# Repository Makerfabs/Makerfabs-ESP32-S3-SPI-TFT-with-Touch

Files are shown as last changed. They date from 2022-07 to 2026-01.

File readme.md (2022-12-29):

# Makerfabs ESP32-S3 SPI TFT with Touch

```c++
/*
Version:		V1.4
Author:			Vincent
Create Date:	2022/7/13
Note:
			2022/12/29	V1.4: Change wiki link
			2022/10/10	V1.3: Add Touch Keyboard demo and Back Light demo.
			2022/8/19	V1.2: Add hardware file.
			2022/8/18	V1.1: Add two demo.
			
*/
```
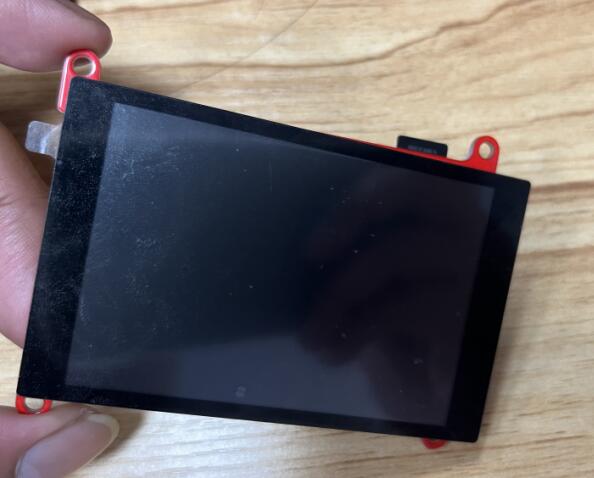
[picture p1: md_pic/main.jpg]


[toc]

# Makerfabs

[Makerfabs home page](https://www.makerfabs.com/)

[Makerfabs Wiki](https://wiki.makerfabs.com/)

# Makerfabs ESP32-S3 SPI TFT with Touch
## Intruduce

Product Link ：[ESP32-S3 SPI TFT with Touch 3.5'' ILI9488](https://www.makerfabs.com/esp32-s3-spi-tft-with-touch-ili9488.html)

Wiki Link : [ESP32-S3 SPI 3.5" TFT with Touch](https://wiki.makerfabs.com/ESP32_S3_SPI_3.5_TFT_with_Touch.html)

The 3.5" 320x480 TFT LCD driver is ILI9488, it uses SPI line for communication with ESP32-S3. You can freely use some of GPIO, to connect the ESP32-S3 display with sensors/ actuators, suitable for IoT applications.

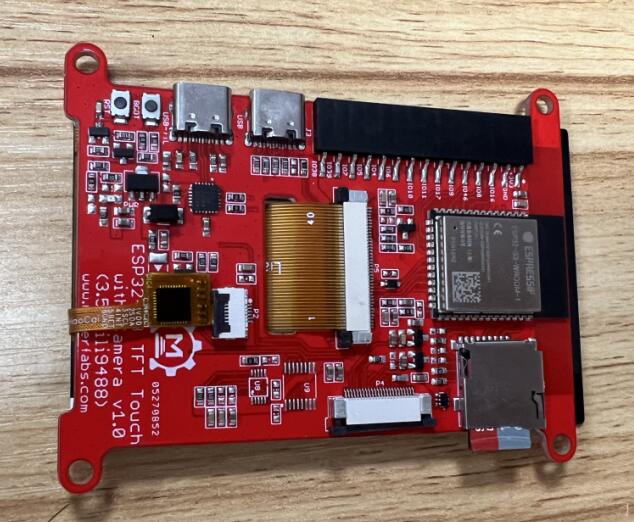
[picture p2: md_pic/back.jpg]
back


## Feature

- Wi-Fi (2.4 GHz band)
- Bluetooth Low Energy
- Dual high performance Xtensa® 32-bit LX7 CPU cores
- Ultra Low Power co-processor running either RISC-V or FSM core
- Multiple peripherals
- Built-in security hardware
- USB OTG interface
- USB Serial/JTAG Controller
- Arduino Compatible: You can play it with Arduino IDE
- LCD 3.5 inch Amorphous-TFT-LCD (Thin Film Transistor Liquid Crystal Display) for mobile-phone or handy electrical equipment
- LCD Driver: ILI9488(SPI)
- LCD Resolution: 320*480
- FT6236 Series ICs are single-chip capacitive touch panel controller IC with a built-in 16 bit enhanced Micro-controller unit (MCU)
- Power supply: 5V, Type-C USB
- Micro SD card slot on the board
- Dual USB Type-C: one for native USB and one for USB-to-UART
- Board size: 66mm * 85mm

# Code Explain

## Complier Option

- Install board : ESP32 .
- Install library : LovyanGFX library. 
- Use type-c use cable connect USB-TTL to PC.
- Upload codes, select "ESP32-S3 DEV Module" and "UART0"

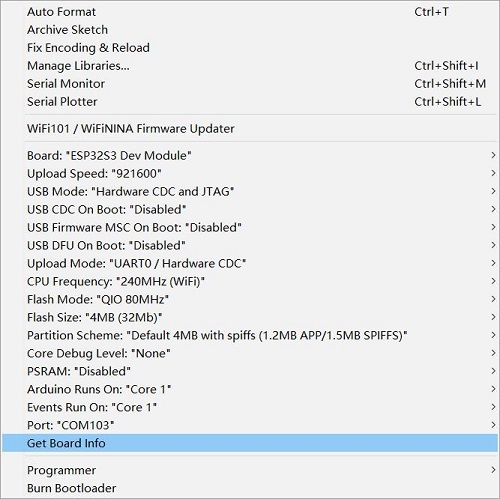
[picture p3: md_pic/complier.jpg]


## Firmware

### S3_9488

A simple test procedure. Touch the black area in the middle of the screen, and the screen starts showing solid colors in turn. Finally, an SD card image is displayed.

## Example

### image_display.ino

The BMP image of the SD card is displayed.

### indoor

[ESP32 Touch_Indoor Environment Expansion](https://www.makerfabs.com/esp32-touch-indoor-environment-expansion.html)

Test air temperature, humidity, and TVOC values with extension plate.

### Touch Keyboard

Added an inherited three custom keyboard keyboard Demo, including text input + key combination, numeric keypad, arrow keys + space.

### Back Light

Periodically adjust the brightness of the backlight

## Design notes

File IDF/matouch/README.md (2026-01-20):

# Example Description
This project includes example code for some MaTouch products.
- [**MaTouch 1.28" ToolSet_Controller**](https://www.makerfabs.com/matouch-1-28-toolset-controller.html)
- [**MaTouch_ESP32-S3 Parallel TFT with Touch 4.3"**](https://www.makerfabs.com/esp32-s3-parallel-tft-with-touch-4-3-inch.html)
- [**Makerfabs-ESP32-S3-SPI-TFT-with-Touch**](#makerfabs-esp32-s3-spi-tft-with-touch)
- [**Makerfabs-ESP32-S3-Parallel-TFT-with-Touch**](#makerfabs-esp32-s3-parallel-tft-with-touch)

This repository is suitable for the [**Makerfabs-ESP32-S3-Parallel-TFT-with-Touch**](#makerfabs-esp32-s3-parallel-tft-with-touch).

## How to use example
#### MaTouch 1.28" ToolSet_Controller
Select the development board as **1-28-gc9a01-cst816s** .

This example includes four routines：
> `main/firmware/1-28-gc9a01-cst816s/release.c`


- xuanniu_test：Example of a rotary encoder.
aadb7e029fc8b3403fd312ede316a084-ezgif.com-optimize
- template_image_switch_lvgl: Use LVGL's built-in libturbo-jpeg decoder to load JPG images from the SD card.
image_switch
- template_lvgl_demos_test: Examples included with LVGL.  
qq_pic_merged_1766452938301
- template_pcf8563_test: A simple PCF8563 RTC example.

#### MaTouch_ESP32-S3 Parallel TFT with Touch 4.3"
Select the development board as **4-3-unkonwn-gt911** .
clipboard_2025-12-22_23-23
This example includes two routines：

> `main/firmware/4-3-unkonwn-gt911/release.c`

clipboard_2025-12-22_23-2
- template_image_switch_lvgl: Use LVGL's built-in libturbo-jpeg decoder to load JPG images from the SD card.
ezgif.com-optimize
- template_lvgl_demos_test: Examples included with LVGL.
qq_pic_merged_1766453592919

#### Makerfabs-ESP32-S3-SPI-TFT-with-Touch

Select the development board as **3-5-ili9488-ft6236** .



This example includes two routines：

> `main/firmware/3-5-ili9488-ft6236/release.c`

```c
static void release_task(void *arg)
{
    template_image_switch_lvgl("/sdcard/images");
    // template_lvgl_demos_test();
    vTaskDelete(NULL);
}
```

- template_image_switch_lvgl: Use LVGL's built-in libturbo-jpeg decoder to load JPG images from the SD card.

  VID20251231133347-ezgif.com-optimize

- template_lvgl_demos_test: Examples included with LVGL.

  ezgif.com-optimize

#### Makerfabs-ESP32-S3-Parallel-TFT-with-Touch

Select the development board as **3-5-ili9488-ft6236** .



This example includes two routines：

> `main/firmware/3-5-ili9488-ft6236/release.c`

```c
static void release_task(void *arg)
{
    template_image_switch_lvgl("/sdcard/images");
    // template_lvgl_demos_test();
    vTaskDelete(NULL);
}
```

- template_image_switch_lvgl: Use LVGL's built-in libturbo-jpeg decoder to load JPG images from the SD card.

  VID20251231133347-ezgif.com-optimize

- template_lvgl_demos_test: Examples included with LVGL.

  ezgif.com-optimize

## Example Note

If using `template_image_switch_lvgl` example, the following options must be enabled in menuconfig.

> Modify line 64 of `managed_components/lvgl__lvgl/env_support/cmake/esp.cmake`:
>
> ```cmake
> REQUIRES esp_timer espressif__libjpeg-turbo)
> ```




If using the `template_lvgl_demos_test` example, enable different LVGL demos in menuconfig.


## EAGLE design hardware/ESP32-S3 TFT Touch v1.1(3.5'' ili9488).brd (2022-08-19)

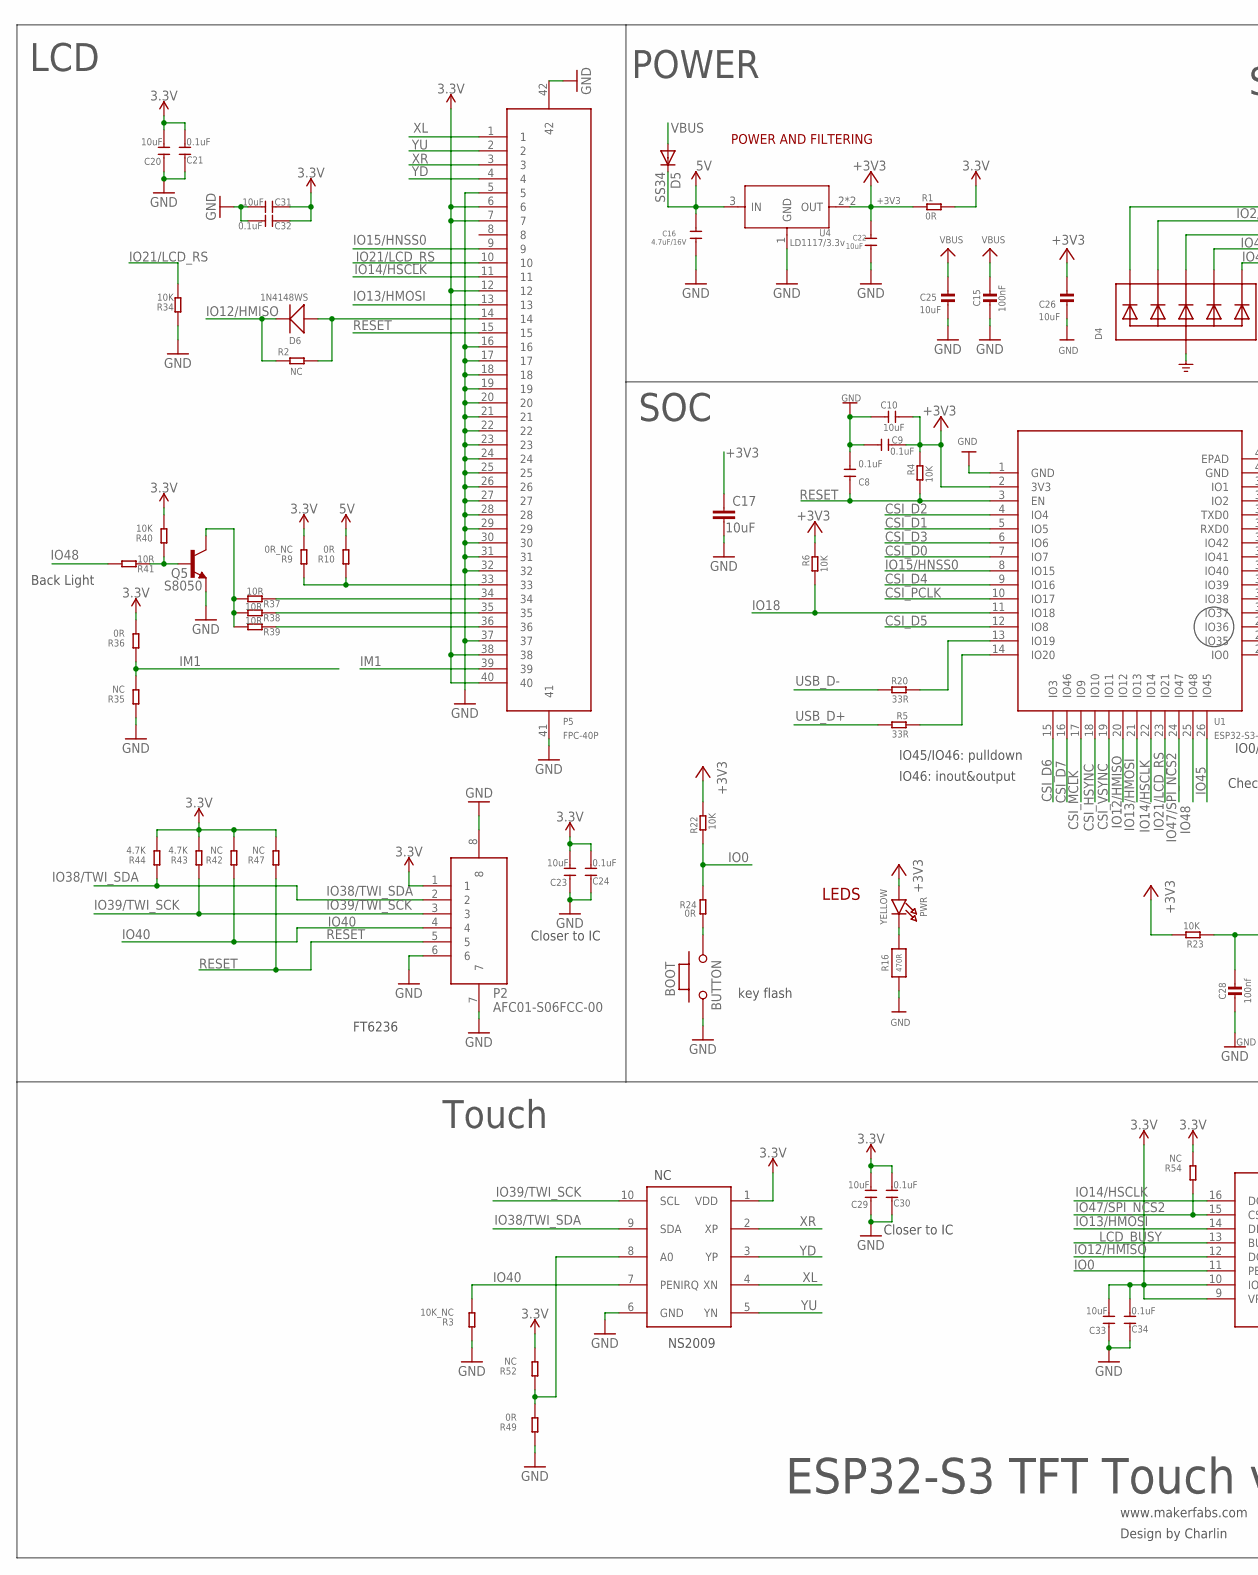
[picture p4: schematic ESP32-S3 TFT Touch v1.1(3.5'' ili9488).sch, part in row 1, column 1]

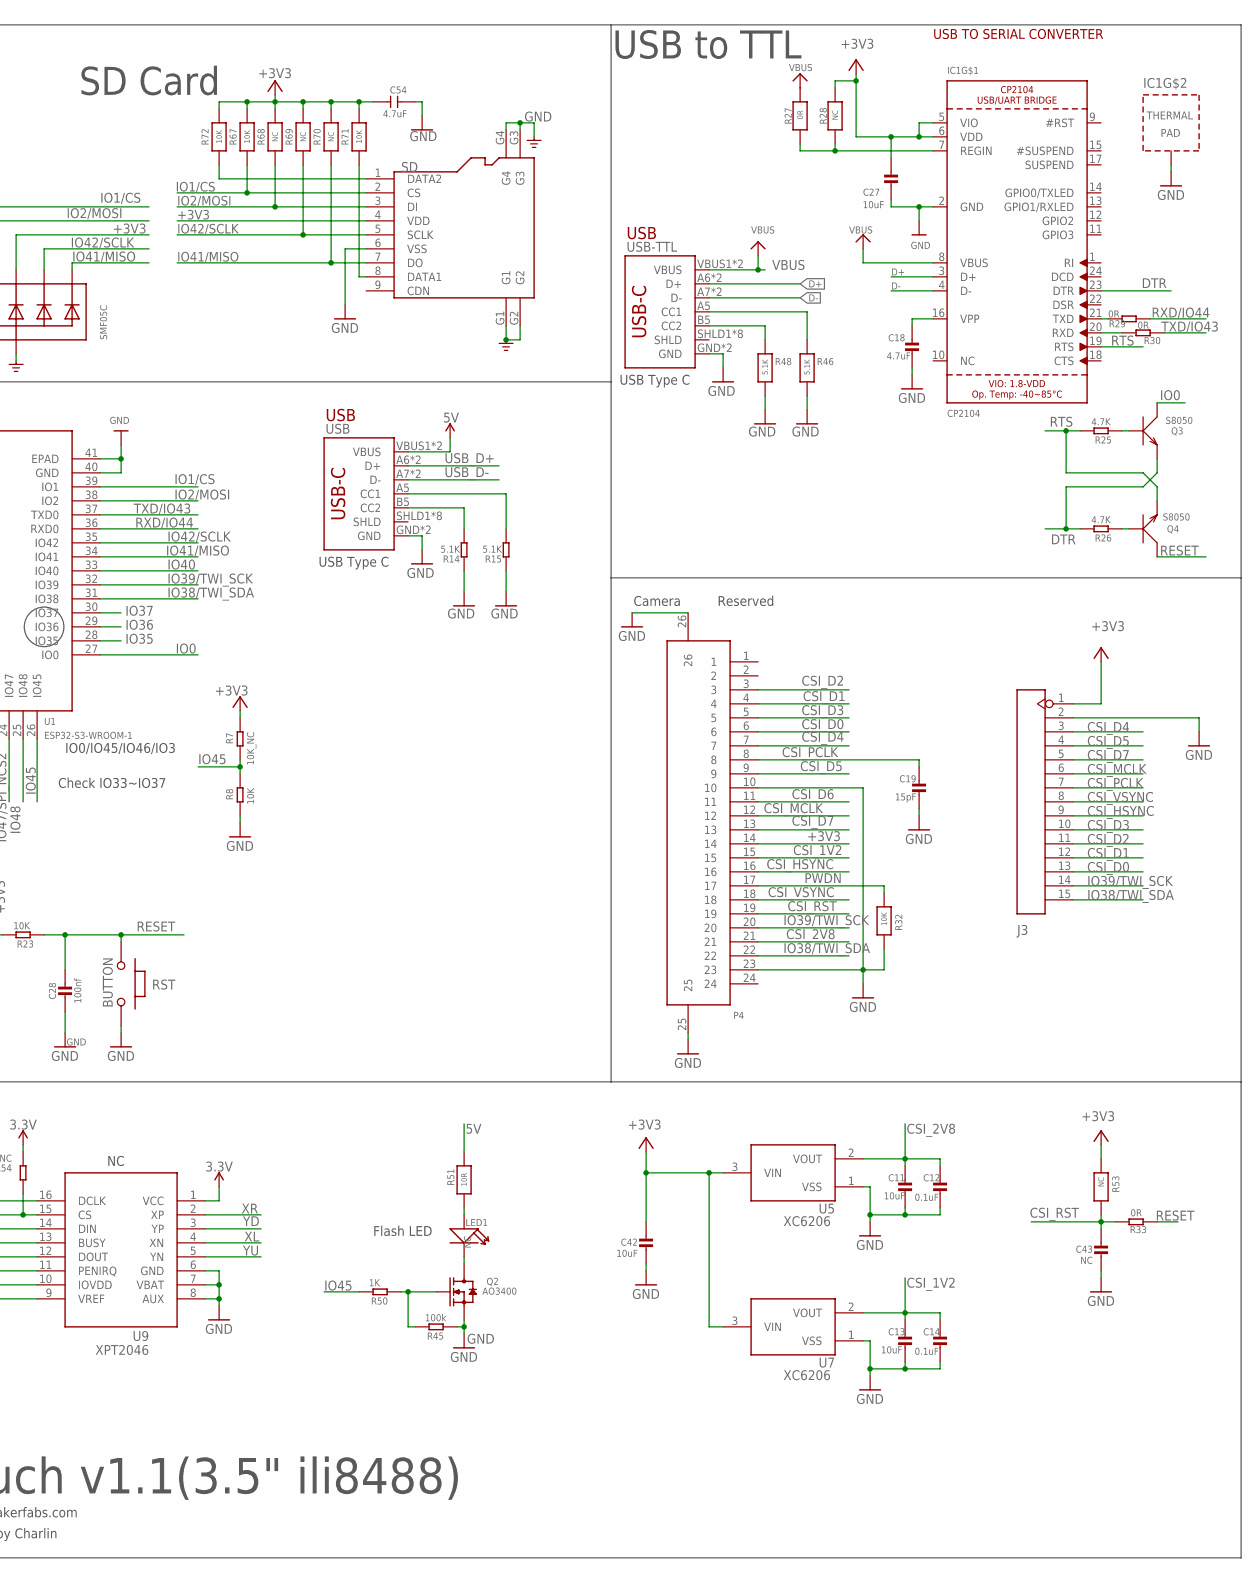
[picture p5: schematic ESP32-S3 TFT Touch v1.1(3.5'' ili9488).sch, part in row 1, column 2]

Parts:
BOOT: BUTTON; 157SW
C8, C9, C21, C24, C30, C32, C34: 0.1uF; DISCRETE_C0603
C10, C20, C23, C29, C31, C33: 10uF; DISCRETE_C0603
C11, C13, C25, C26, C27, C42: 10uF; 0603-NO
C12, C14: 0.1uF; 0603-NO
C15: 100nF; 0603-NO
C16: 4.7uF/16V; 0603
C17: 10uF; C0603
C18: 4.7uF; 0603-NO
C19: 15pF; 0603-NO
C22: 10uF; 0603
C28: 100nf; 0603-NO
C43: NC; 0603-NO
C54: 4.7uF; DISCRETE_C0603
D4: SMF05C; SOT363
D5: SS34; DO-214AC
D6: 1N4148WS; SOD323
IC1: CP2104; QFN24_4MM_SMSC
J3: HEADER-1X15P; SMD15-2.54P8.5H
LED1: NC; DISCRETE_LED-3528
P2: AFC01-S06FCC-00; SMD8-50P-740L535W
P4: FPC-24P; SMD26-50P-1760L450W
P5: FPC-40P; SMD42-50P-2560L490W
PWR: YELLOW; CHIPLED_0805_NOOUTLINE
Q2: AO3400; SOT23@1
Q3, Q4: S8050; SOT23
Q5: S8050; SPARKFUN_SOT23
R1, R24, R29, R30, R33: 0R; R0603
R2: NC; R0603
R3: 10K_NC; DISCRETE_R0603
R4, R6, R8, R22, R23: 10K; R0603
R5, R20: 33R; R0603
R7: 10K_NC; R0603
R9: 0R_NC; DISCRETE_R0603
R10, R36, R49: 0R; DISCRETE_R0603
R14, R15: 5.1K; DISCRETE_R0603
R16: 470R; 0603-NO
R25, R26: 4.7K; R0603
R27: 0R; 0603-NO
R28, R53, R68, R69, R70: NC; 0603-NO
R32, R67, R71, R72: 10K; 0603-NO
R34, R40: 10K; DISCRETE_R0603
R35, R42, R47, R52, R54: NC; DISCRETE_R0603
R37, R38, R39, R41: 10R; DISCRETE_R0603
R43, R44: 4.7K; DISCRETE_R0603
R45: 100k; R0603
R46, R48: 5.1K; 0603-NO
R50: 1K; R0603
R51: 10R; 0603-NO
RST: BUTTON; 157SW
SD: HOLDER-MICROSD-9P; 9P-SMD-W/-RING
U1: ESP32-S3-WROOM-1
U4: LD1117/3.3v; SOT89
U5, U7: XC6206; SOT-23
U8: NS2009; MSOP10
U9: XPT2046; TSSOP16-65P-560L910W
USB: USB_C5; USB-C-16P-5
USB-TTL: USB_C5; USB-C-16P-5

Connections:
3.3V: C20.2, C21.2, C23.2, C24.2, C29.2, C30.2, C31.1, C32.1, C33.2, C34.2, P2.1, P5.6, P5.7, P5.12, P5.38, P5.40, R1.2, R9.2, R36.2, R40.2, R42.2, R43.2, R44.2, R47.2, R52.2, R54.2, U8.1 (VDD), U9.1 (VCC), U9.9 (VREF), U9.10 (IOVDD)
5V: C16.1, D5.C, R10.2, R51.1, U4.3 (IN), USB.VBUS1 (VBUS), USB.VBUS2 (VBUS)
+3V3: C9.1, C10.1, C17.1, C22.1, C26.1, C27.1, C42.1, C54.2, D4.4 (C3), IC1.5 (VIO), IC1.6 (VDD), J3.1, P4.14, PWR.A, R1.1, R4.2, R6.2, R7.2, R22.2, R23.2, R28.1, R53.1, R67.2, R68.2, R69.2, R70.2, R71.2, R72.2, SD.4 (VDD), U1.2 (3V3), U4.2 (OUT), U4.4 (OUT), U5.3 (VIN), U7.3 (VIN)
CSI_1V2: C13.1, C14.1, P4.15, U7.2 (VOUT)
CSI_2V8: C11.1, C12.1, P4.21, U5.2 (VOUT)
CSI_D0: J3.13, P4.6, U1.7 (IO7)
CSI_D1: J3.12, P4.4, U1.5 (IO5)
CSI_D2: J3.11, P4.3, U1.4 (IO4)
CSI_D3: J3.10, P4.5, U1.6 (IO6)
CSI_D4: J3.3, P4.7, U1.9 (IO16)
CSI_D5: J3.4, P4.9, U1.12 (IO8)
CSI_D6: P4.11, U1.15 (IO3)
CSI_D7: J3.5, P4.13, U1.16 (IO46)
CSI_HSYNC: J3.9, P4.16, U1.18 (IO10)
CSI_MCLK: J3.6, P4.12, U1.17 (IO9)
CSI_PCLK: C19.1, J3.7, P4.8, U1.10 (IO17)
CSI_RST: C43.1, P4.19, R33.2, R53.2
CSI_VSYNC: J3.8, P4.18, U1.19 (IO11)
D+: IC1.3 (D+), USB-TTL.A6 (D+), USB-TTL.B6 (D+)
D-: IC1.4 (D-), USB-TTL.A7 (D-), USB-TTL.B7 (D-)
DTR: IC1.23 (DTR), Q3.2 (E), R26.2
GND: BOOT.1, C8.2, C9.2, C10.2, C11.2, C12.2, C13.2, C14.2, C15.2, C16.2, C17.2, C18.2, C19.2, C20.1, C21.1, C22.2, C23.1, C24.1, C25.2, C26.2, C27.2, C28.2, C29.1, C30.1, C31.2, C32.2, C33.1, C34.1, C42.2, C43.2, C54.1, D4.2 (A), IC1.2 (GND), IC1.THERM (TP), J3.2, P2.6, P2.7, P2.8, P4.10, P4.23, P4.25, P4.26, P5.5, P5.16, P5.17, P5.18, P5.19, P5.20, P5.21, P5.22, P5.23, P5.24, P5.25, P5.26, P5.27, P5.28, P5.29, P5.30, P5.31, P5.32, P5.37, P5.41, P5.42, Q2.2 (S), Q5.2 (E), R3.1, R8.1, R14.1, R15.1, R16.1, R32.2, R34.1, R35.1, R45.1, R46.2, R48.2, R49.1, RST.1, SD.6 (VSS), SD.G1, SD.G2, SD.G3, SD.G4, U1.1 (GND), U1.40 (GND), U1.41 (EPAD), U4.1 (GND), U5.1 (VSS), U7.1 (VSS), U8.6 (GND), U9.6 (GND), U9.7 (VBAT), U9.8 (AUX), USB.GND, USB.GND2 (GND), USB-TTL.GND, USB-TTL.GND2 (GND)
IM1: P5.39, R35.2, R36.1
IO0: Q3.3 (C), R22.1, R24.2, U1.27 (IO0), U9.11 (PENIRQ)
IO1/CS: D4.1 (C1), R67.1, SD.2 (CS), U1.39 (IO1)
IO2/MOSI: D4.3 (C2), R68.1, SD.3 (DI), U1.38 (IO2)
IO12/HMISO: D6.-, R2.1, U1.20 (IO12), U9.12 (DOUT)
IO13/HMOSI: P5.13, U1.21 (IO13), U9.14 (DIN)
IO14/HSCLK: P5.11, U1.22 (IO14), U9.16 (DCLK)
IO15/HNSS0: P5.9, U1.8 (IO15)
IO18: R6.1, U1.11 (IO18)
IO21/LCD_RS: P5.10, R34.2, U1.23 (IO21)
IO35: U1.28 (IO35)
IO36: U1.29 (IO36)
IO37: U1.30 (IO37)
IO38/TWI_SDA: J3.15, P2.2, P4.22, R44.1, U1.31 (IO38), U8.9 (SDA)
IO39/TWI_SCK: J3.14, P2.3, P4.20, R43.1, U1.32 (IO39), U8.10 (SCL)
IO40: P2.4, R3.2, R42.1, U1.33 (IO40), U8.7 (PENIRQ)
IO41/MISO: D4.6 (C5), R70.1, SD.7 (DO), U1.34 (IO41)
IO42/SCLK: D4.5 (C4), R69.1, SD.5 (SCLK), U1.35 (IO42)
IO45: R7.1, R8.2, R50.2, U1.26 (IO45)
IO47/SPI_NCS2: R54.1, U1.24 (IO47), U9.15 (CS)
IO48: R41.2, U1.25 (IO48)
LCD_BUSY: U9.13 (BUSY)
unnamed: C18.1, IC1.16 (VPP)
unnamed: Q4.1 (B), R26.1
unnamed: Q3.1 (B), R25.1
unnamed: D6.+, P5.14, R2.2
unnamed: Q2.1 (G), R45.2, R50.1
unnamed: BOOT.2, R24.1
unnamed: PWR.C, R16.2
unnamed: LED1.1 (+), R51.2
unnamed: LED1.2 (-), Q2.3 (D)
unnamed: R46.1, USB-TTL.A5 (CC1)
unnamed: R48.1, USB-TTL.B5 (CC2)
unnamed: IC1.7 (REGIN), R27.2, R28.2
unnamed: R15.2, USB.A5 (CC1)
unnamed: R20.2, U1.13 (IO19)
unnamed: R5.2, U1.14 (IO20)
unnamed: R14.2, USB.B5 (CC2)
unnamed: IC1.21 (TXD), R29.2
unnamed: IC1.20 (RXD), R30.2
unnamed: P5.34, R37.1
unnamed: P5.35, R38.1
unnamed: P5.36, R39.1
unnamed: Q5.1 (B), R40.1, R41.1
unnamed: Q5.3 (C), R37.2, R38.2, R39.2
unnamed: R49.2, R52.1, U8.8 (A0)
unnamed: P5.33, R9.1, R10.1
unnamed: R72.1, SD.1 (DATA2)
unnamed: R71.1, SD.8 (DATA1)
PWDN: P4.17, R32.1
RESET: C8.1, C28.1, P2.5, P5.15, Q4.3 (C), R4.1, R23.1, R33.1, R47.1, RST.2, U1.3 (EN)
RTS: IC1.19 (RTS), Q4.2 (E), R25.2
RXD/IO44: R29.1, U1.36 (RXD0)
TXD/IO43: R30.1, U1.37 (TXD0)
USB_D+: R5.1, USB.A6 (D+), USB.B6 (D+)
USB_D-: R20.1, USB.A7 (D-), USB.B7 (D-)
VBUS: C15.1, C25.1, D5.A, IC1.8 (VBUS), R27.1, USB-TTL.VBUS1 (VBUS), USB-TTL.VBUS2 (VBUS)
XL: P5.1, U8.4 (XN), U9.4 (XN)
XR: P5.3, U8.2 (XP), U9.2 (XP)
YD: P5.4, U8.3 (YP), U9.3 (YP)
YU: P5.2, U8.5 (YN), U9.5 (YN)

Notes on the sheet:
www.makerfabs.com
Design by Charlin
USB
LEDS
POWER AND FILTERING
USB TO SERIAL CONVERTER
key flash
ESP32-S3 TFT Touch v1.1(3.5" ili8488)
POWER
USB to TTL
USB Type C
SD Card
Flash LED
Camera
NS2009
FT6236
Closer to IC
Back Light
IO45/IO46: pulldown
IO46: inout&output
IO0/IO45/IO46/IO3
Check IO33~IO37
LCD
SOC
Touch
Reserved

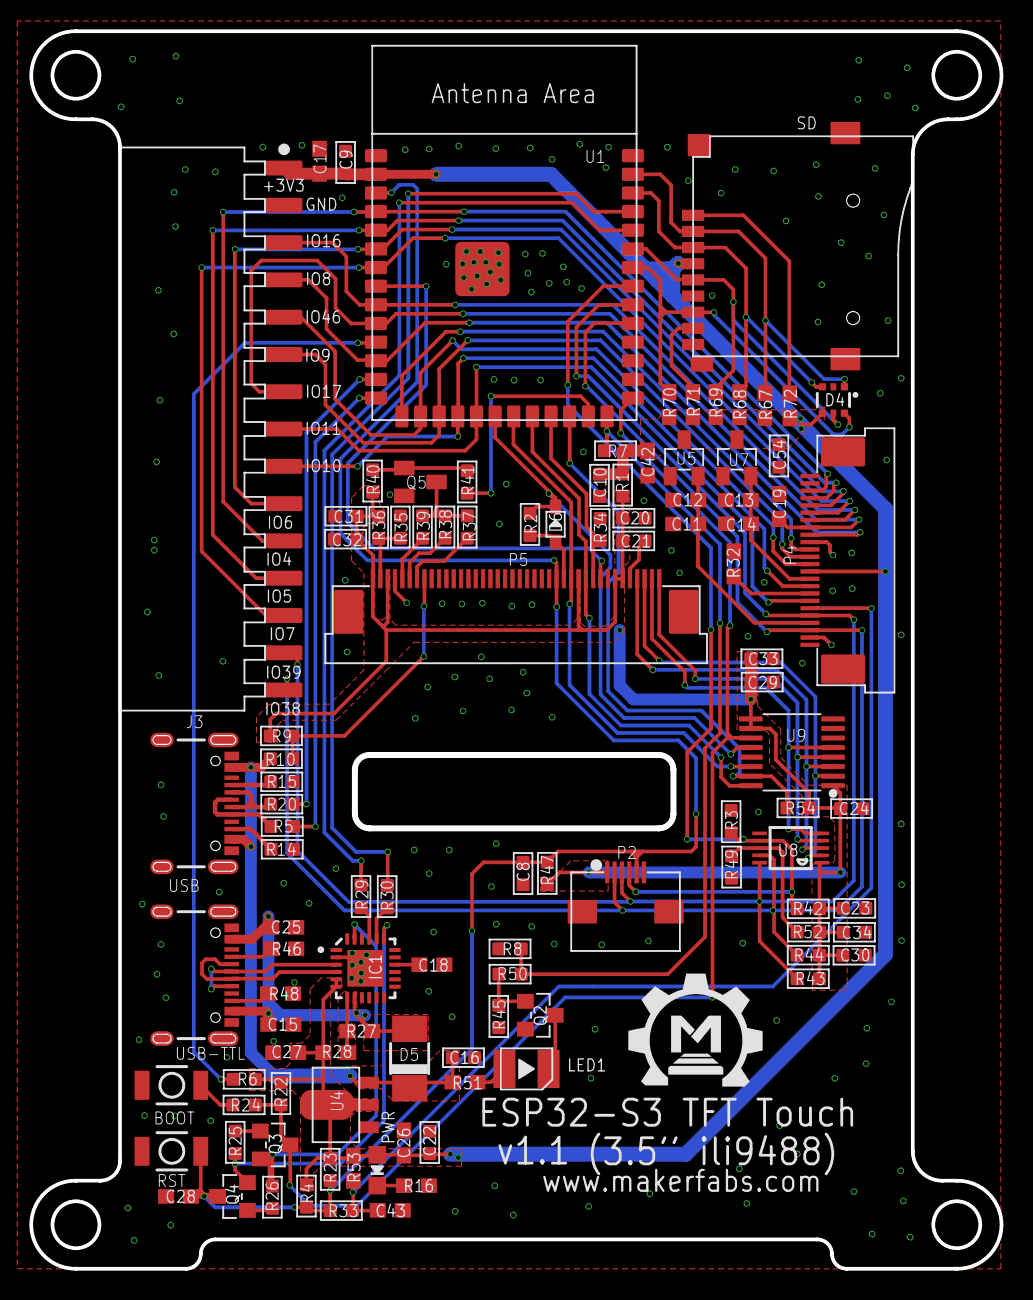
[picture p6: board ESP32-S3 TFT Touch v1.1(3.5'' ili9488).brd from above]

Board: 2 copper layers, 66.1 x 84.3 mm, 108 parts (0 on the bottom side), 79 nets.

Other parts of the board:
U$1: MAKERFABS_0.3

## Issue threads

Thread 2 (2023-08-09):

Slight bug...

phpbbireland, 2023-08-09:
In Button.h, you need to change #include <arduino.h> to #include <Arduino.h>
Windows doesn't care but Linux is case sensitive and it throw an compile error...

Mike

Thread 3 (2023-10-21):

SPI @ 80 MHz - Makerfabs-ESP32-S3-SPI-TFT-with-Touch

chbarg, 2023-10-21:
Hello,
I have the display working with an SPI clock frequency of 40 MHz. When I tried 80 MHz, the screen shows all sort of noise.
Is there any recommendation on how to boost the clock speed to 80 MHz? Hardware, software?
I am using LGFX.

It seems like there is a power issue too. I tend to have more power glitches when the display updates right after an UART transmission. Backlight seems to flicker. I need to connect the scope to see what is happening.

I am comparing the board to a WT32-SC01 (ESP32, SPI display). That board runs at 80 MHz.

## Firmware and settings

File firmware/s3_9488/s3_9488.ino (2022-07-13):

//测试通过
#define LGFX_USE_V1

#include <LovyanGFX.hpp>
#include <vector>
#include <SPI.h>
#include <SD.h>
#include <FS.h>

#include "FT6236.h"
const int i2c_touch_addr = TOUCH_I2C_ADD;
#define get_pos ft6236_pos

#define LCD_MOSI 13
#define LCD_MISO 12 // 12
#define LCD_SCK 14
#define LCD_CS 15
#define LCD_RST -1 // 26
#define LCD_DC 21  // 33
#define LCD_BL -1

#define I2C_SDA 38
#define I2C_SCL 39

#define SD_MOSI 2
#define SD_MISO 41
#define SD_SCK 42
#define SD_CS 1

class LGFX : public lgfx::LGFX_Device
{
    // lgfx::Panel_ILI9341 _panel_instance;
    lgfx::Panel_ILI9488 _panel_instance;
    lgfx::Bus_SPI _bus_instance;

public:
    // コンストラクタを作成し、ここで各種設定を行います。
    // クラス名を変更した場合はコンストラクタも同じ名前を指定してください。
    LGFX(void)
    {
        {                                      // バス制御の設定を行います。
            auto cfg = _bus_instance.config(); // バス設定用の構造体を取得します。

            // SPIバスの設定
            cfg.spi_host = SPI3_HOST;  // 使用するSPIを選択  (VSPI_HOST or HSPI_HOST)
            cfg.spi_mode = 0;          // SPI通信モードを設定 (0 ~ 3)
            cfg.freq_write = 40000000; // 送信時のSPIクロック (最大80MHz, 80MHzを整数で割った値に丸められます)
            cfg.freq_read = 16000000;  // 受信時のSPIクロック
            cfg.spi_3wire = true;      // 受信をMOSIピンで行う場合はtrueを設定
            cfg.use_lock = true;       // トランザクションロックを使用する場合はtrueを設定
            cfg.dma_channel = 1;       // Set the DMA channel (1 or 2. 0=disable)   使用するDMAチャンネルを設定 (0=DMA不使用)
            cfg.pin_sclk = LCD_SCK;    // SPIのSCLKピン番号を設定
            cfg.pin_mosi = LCD_MOSI;   // SPIのMOSIピン番号を設定
            cfg.pin_miso = LCD_MISO;   // SPIのMISOピン番号を設定 (-1 = disable)
            cfg.pin_dc = LCD_DC;       // SPIのD/Cピン番号を設定  (-1 = disable)
                                       // SDカードと共通のSPIバスを使う場合、MISOは省略せず必ず設定してください。

            _bus_instance.config(cfg);              // 設定値をバスに反映します。
            _panel_instance.setBus(&_bus_instance); // バスをパネルにセットします。
        }

        {                                        // 表示パネル制御の設定を行います。
            auto cfg = _panel_instance.config(); // 表示パネル設定用の構造体を取得します。

            cfg.pin_cs = LCD_CS;   // CSが接続されているピン番号   (-1 = disable)
            cfg.pin_rst = LCD_RST; // RSTが接続されているピン番号  (-1 = disable)
            cfg.pin_busy = -1;     // BUSYが接続されているピン番号 (-1 = disable)

            // ※ 以下の設定値はパネル毎に一般的な初期値が設定されていますので、不明な項目はコメントアウトして試してみてください。

            cfg.memory_width = 320;   // ドライバICがサポートしている最大の幅
            cfg.memory_height = 480;  // ドライバICがサポートしている最大の高さ
            cfg.panel_width = 320;    // 実際に表示可能な幅
            cfg.panel_height = 480;   // 実際に表示可能な高さ
            cfg.offset_x = 0;         // パネルのX方向オフセット量
            cfg.offset_y = 0;         // パネルのY方向オフセット量
            cfg.offset_rotation = 0;  // 回転方向の値のオフセット 0~7 (4~7は上下反転)
            cfg.dummy_read_pixel = 8; // ピクセル読出し前のダミーリードのビット数
            cfg.dummy_read_bits = 1;  // ピクセル以外のデータ読出し前のダミーリードのビット数
            cfg.readable = true;      // データ読出しが可能な場合 trueに設定
            cfg.invert = false;       // パネルの明暗が反転してしまう場合 trueに設定
            cfg.rgb_order = false;    // パネルの赤と青が入れ替わってしまう場合 trueに設定
            cfg.dlen_16bit = false;   // データ長を16bit単位で送信するパネルの場合 trueに設定
            cfg.bus_shared = true;    // SDカードとバスを共有している場合 trueに設定(drawJpgFile等でバス制御を行います)

            _panel_instance.config(cfg);
        }

        setPanel(&_panel_instance); // 使用するパネルをセットします。
    }
};

LGFX lcd;

SPIClass SD_SPI;

void setup(void)
{
    Serial.begin(115200);

    lcd.init();
    lcd.fillScreen(TFT_WHITE);

    lcd.setTextSize(3);

    sd_init();
    touch_init();

    lcd.fillRect(80, 160, 160, 160, TFT_BLACK);
    lcd.setCursor(90, 180);
    lcd.println(" TOUCH");
    lcd.setCursor(90, 210);
    lcd.println("  TO");
    lcd.setCursor(90, 240);
    lcd.println("CONTINUE");

    int pos[2] = {0, 0};

    while (1)
    {
        get_pos(pos);

        if (pos[0] > 80 && pos[0] < 240 && pos[1] > 160 && pos[1] < 320)
            break;
        delay(100);
    }
}

static int colors[] = {TFT_RED, TFT_GREEN, TFT_BLUE, TFT_CYAN, TFT_MAGENTA, TFT_YELLOW};

int i = 0;

void loop(void)
{
    /*
    // fps
    static int prev_sec;
    static int fps;
    ++fps;
    int sec = millis() / 1000;
    if (prev_sec != sec)
    {
        prev_sec = sec;
        lcd.setCursor(0, 440);
        lcd.setTextSize(4);
        lcd.printf("fps:%03d", fps);
        fps = 0;
    }

    lcd.fillRect(0, 0, 320, 440, colors[i++]);
    */

    lcd.fillScreen(colors[i++]);
    delay(1000);

    if (i > 5)
    {
        i = 0;
        lcd.setRotation(3);
        print_img(SD, "/logo.bmp", 480, 320);
        delay(1000);
    }
}

void sd_init()
{
    SD_SPI.begin(SD_SCK, SD_MISO, SD_MOSI);
    if (!SD.begin(SD_CS, SD_SPI, 40000000))
    {
        Serial.println("Card Mount Failed");
        lcd.setCursor(10, 10);
        lcd.println("SD Card Failed");
        while (1)
            delay(1000);
    }
    else
    {
        Serial.println("Card Mount Successed");
    }

    Serial.println("SD init over.");

    /*

    uint8_t cardType = SD.cardType();

    Serial.print("SD Card Type: ");
    if (cardType == CARD_NONE)
    {
        Serial.println("No SD card attached");
    }
    else if (cardType == CARD_MMC)
    {
        Serial.println("MMC");
    }
    else if (cardType == CARD_SD)
    {
        Serial.println("SDSC");
    }
    else if (cardType == CARD_SDHC)
    {
        Serial.println("SDHC");
    }
    else
    {
        Serial.println("UNKNOWN");
    }

    uint64_t cardSize = SD.cardSize() / (1024 * 1024);
    Serial.printf("SD Card Size: %lluMB\n", cardSize);

    listDir(SD, "/", 0);
    createDir(SD, "/mydir");
    listDir(SD, "/", 0);
    removeDir(SD, "/mydir");
    listDir(SD, "/", 2);
    writeFile(SD, "/hello.txt", "Hello ");
    appendFile(SD, "/hello.txt", "World!\n");
    readFile(SD, "/hello.txt");
    deleteFile(SD, "/foo.txt");
    renameFile(SD, "/hello.txt", "/foo.txt");
    readFile(SD, "/foo.txt");
    testFileIO(SD, "/test.txt");
    Serial.printf("Total space: %lluMB\n", SD.totalBytes() / (1024 * 1024));
    Serial.printf("Used space: %lluMB\n", SD.usedBytes() / (1024 * 1024));
    */
}

void touch_init()
{
    // I2C init
    Wire.begin(I2C_SDA, I2C_SCL);
    byte error, address;

    Wire.beginTransmission(i2c_touch_addr);
    error = Wire.endTransmission();

    if (error == 0)
    {
        Serial.print("I2C device found at address 0x");
        Serial.print(i2c_touch_addr, HEX);
        Serial.println("  !");
    }
    else if (error == 4)
    {
        Serial.print("Unknown error at address 0x");
        Serial.println(i2c_touch_addr, HEX);
        lcd.setCursor(10, 40);
        lcd.println("Touch Failed");
    }
}

// Display image from file
int print_img(fs::FS &fs, String filename, int x, int y)
{

    File f = fs.open(filename, "r");
    if (!f)
    {
        Serial.println("Failed to open file for reading");
        f.close();
        return 0;
    }

    f.seek(54);
    int X = x;
    int Y = y;
    uint8_t RGB[3 * X];
    for (int row = 0; row < Y; row++)
    {
        f.seek(54 + 3 * X * row);
        f.read(RGB, 3 * X);

        lcd.pushImage(0, row, X, 1, (lgfx::rgb888_t *)RGB);
    }

    f.close();
    return 0;
}

// SD test

void listDir(fs::FS &fs, const char *dirname, uint8_t levels)
{
    Serial.printf("Listing directory: %s\n", dirname);

    File root = fs.open(dirname);
    if (!root)
    {
        Serial.println("Failed to open directory");
        return;
    }
    if (!root.isDirectory())
    {
        Serial.println("Not a directory");
        return;
    }

    File file = root.openNextFile();
    while (file)
    {
        if (file.isDirectory())
        {
            Serial.print("  DIR : ");
            Serial.println(file.name());
            if (levels)
            {
                listDir(fs, file.name(), levels - 1);
            }
        }
        else
        {
            Serial.print("  FILE: ");
            Serial.print(file.name());
            Serial.print("  SIZE: ");
            Serial.println(file.size());
        }
        file = root.openNextFile();
    }
}

void createDir(fs::FS &fs, const char *path)
{
    Serial.printf("Creating Dir: %s\n", path);
    if (fs.mkdir(path))
    {
        Serial.println("Dir created");
    }
    else
    {
        Serial.println("mkdir failed");
    }
}

void removeDir(fs::FS &fs, const char *path)
{
    Serial.printf("Removing Dir: %s\n", path);
    if (fs.rmdir(path))
    {
        Serial.println("Dir removed");
    }
    else
    {
        Serial.println("rmdir failed");
    }
}

void readFile(fs::FS &fs, const char *path)
{
    Serial.printf("Reading file: %s\n", path);

    File file = fs.open(path);
    if (!file)
    {
        Serial.println("Failed to open file for reading");
        return;
    }

    Serial.print("Read from file: ");
    while (file.available())
    {
        Serial.write(file.read());
    }
    file.close();
}

void writeFile(fs::FS &fs, const char *path, const char *message)
{
    Serial.printf("Writing file: %s\n", path);

    File file = fs.open(path, FILE_WRITE);
    if (!file)
    {
        Serial.println("Failed to open file for writing");
        return;
    }
    if (file.print(message))
    {
        Serial.println("File written");
    }
    else
    {
        Serial.println("Write failed");
    }
    file.close();
}

void appendFile(fs::FS &fs, const char *path, const char *message)
{
    Serial.printf("Appending to file: %s\n", path);

    File file = fs.open(path, FILE_APPEND);
    if (!file)
    {
        Serial.println("Failed to open file for appending");
        return;
    }
    if (file.print(message))
    {
        Serial.println("Message appended");
    }
    else
    {
        Serial.println("Append failed");
    }
    file.close();
}

void renameFile(fs::FS &fs, const char *path1, const char *path2)
{
    Serial.printf("Renaming file %s to %s\n", path1, path2);
    if (fs.rename(path1, path2))
    {
        Serial.println("File renamed");
    }
    else
    {
        Serial.println("Rename failed");
    }
}

void deleteFile(fs::FS &fs, const char *path)
{
    Serial.printf("Deleting file: %s\n", path);
    if (fs.remove(path))
    {
        Serial.println("File deleted");
    }
    else
    {
        Serial.println("Delete failed");
    }
}

void testFileIO(fs::FS &fs, const char *path)
{
    File file = fs.open(path);
    static uint8_t buf[512];
    size_t len = 0;
    uint32_t start = millis();
    uint32_t end = start;
    if (file)
    {
        len = file.size();
        size_t flen = len;
        start = millis();
        while (len)
        {
            size_t toRead = len;
            if (toRead > 512)
            {
                toRead = 512;
            }
            file.read(buf, toRead);
            len -= toRead;
        }
        end = millis() - start;
        Serial.printf("%u bytes read for %u ms\n", flen, end);
        file.close();
    }
    else
    {
        Serial.println("Failed to open file for reading");
    }

    file = fs.open(path, FILE_WRITE);
    if (!file)
    {
        Serial.println("Failed to open file for writing");
        return;
    }

    size_t i;
    start = millis();
    for (i = 0; i < 2048; i++)
    {
        file.write(buf, 512);
    }
    end = millis() - start;
    Serial.printf("%u bytes written for %u ms\n", 2048 * 512, end);
    file.close();
}

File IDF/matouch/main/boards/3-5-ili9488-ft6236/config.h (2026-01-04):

#ifndef _BOARD_CONFIG_H_
#define _BOARD_CONFIG_H_

#include <driver/gpio.h>

#define AUDIO_INPUT_SAMPLE_RATE  16000
#define AUDIO_OUTPUT_SAMPLE_RATE 16000


#define SPI2_MOSI_PIN   GPIO_NUM_2
#define SPI2_MISO_PIN   GPIO_NUM_41
#define SPI2_CLK_PIN    GPIO_NUM_42

#if CONFIG_3_5_IlI9488_SPI_FT6236

#define SPI3_MOSI_PIN   GPIO_NUM_13
#define SPI3_MISO_PIN   GPIO_NUM_12
#define SPI3_CLK_PIN    GPIO_NUM_14

#else

#define SPI3_MOSI_PIN   GPIO_NUM_13
#define SPI3_MISO_PIN   GPIO_NUM_12
#define SPI3_CLK_PIN    GPIO_NUM_18

#endif


// 如果使用 Duplex I2S 模式，请注释下面一行
// #define AUDIO_I2S_METHOD_SIMPLEX

#ifdef AUDIO_I2S_METHOD_SIMPLEX

#define AUDIO_I2S_MIC_GPIO_WS       GPIO_NUM_2
#define AUDIO_I2S_MIC_GPIO_SCK      GPIO_NUM_42
#define AUDIO_I2S_MIC_GPIO_DIN      GPIO_NUM_41
#define AUDIO_I2S_SPK_GPIO_DOUT     GPIO_NUM_19
#define AUDIO_I2S_SPK_GPIO_BCLK     GPIO_NUM_20
#define AUDIO_I2S_SPK_GPIO_LRCK     GPIO_NUM_1

#else

#define AUDIO_I2S_GPIO_WS           GPIO_NUM_43
#define AUDIO_I2S_GPIO_BCLK         GPIO_NUM_44
#define AUDIO_I2S_GPIO_DIN          GPIO_NUM_2
#define AUDIO_I2S_GPIO_DOUT         GPIO_NUM_19

#endif


#define BUILTIN_LED_GPIO            GPIO_NUM_NC
#define BOOT_BUTTON_GPIO            GPIO_NUM_0
#define TOUCH_BUTTON_GPIO           GPIO_NUM_NC
#define VOLUME_UP_BUTTON_GPIO       GPIO_NUM_NC
#define VOLUME_DOWN_BUTTON_GPIO     GPIO_NUM_NC

#define DISPLAY_MOSI_PIN            SPI3_MOSI_PIN
#define DISPLAY_MISO_PIN            SPI3_MISO_PIN
#define DISPLAY_CLK_PIN             SPI3_CLK_PIN

#if CONFIG_3_5_IlI9488_SPI_FT6236
#define DISPLAY_BACKLIGHT_PIN       GPIO_NUM_48
#define DISPLAY_DC_PIN              GPIO_NUM_21
#define DISPLAY_RST_PIN             GPIO_NUM_NC
#define DISPLAY_CS_PIN              GPIO_NUM_15
#define DISPLAY_RD_PIN              GPIO_NUM_48

#else

#define DISPLAY_BACKLIGHT_PIN       GPIO_NUM_45
#define DISPLAY_DC_PIN              GPIO_NUM_17
#define DISPLAY_RST_PIN             GPIO_NUM_NC
#define DISPLAY_CS_PIN              GPIO_NUM_46
#define DISPLAY_RD_PIN              GPIO_NUM_48
#endif


#define EXAMPLE_LCD_IO_DATA0        GPIO_NUM_47
#define EXAMPLE_LCD_IO_DATA1        GPIO_NUM_21
#define EXAMPLE_LCD_IO_DATA2        GPIO_NUM_14
#define EXAMPLE_LCD_IO_DATA3        GPIO_NUM_13
#define EXAMPLE_LCD_IO_DATA4        GPIO_NUM_12
#define EXAMPLE_LCD_IO_DATA5        GPIO_NUM_11
#define EXAMPLE_LCD_IO_DATA6        GPIO_NUM_10
#define EXAMPLE_LCD_IO_DATA7        GPIO_NUM_9
#define EXAMPLE_LCD_IO_DATA8        GPIO_NUM_3
#define EXAMPLE_LCD_IO_DATA9        GPIO_NUM_8
#define EXAMPLE_LCD_IO_DATA10       GPIO_NUM_16
#define EXAMPLE_LCD_IO_DATA11       GPIO_NUM_15
#define EXAMPLE_LCD_IO_DATA12       GPIO_NUM_7
#define EXAMPLE_LCD_IO_DATA13       GPIO_NUM_6
#define EXAMPLE_LCD_IO_DATA14       GPIO_NUM_5
#define EXAMPLE_LCD_IO_DATA15       GPIO_NUM_4




#define TOUCH_SDA_PIN               GPIO_NUM_38
#define TOUCH_SCL_PIN               GPIO_NUM_39
#define TOUCH_INT_PIN               GPIO_NUM_NC
#define TOUCH_RST_PIN               GPIO_NUM_NC

#define SDCARD_MOUNT_POINT          "/sdcard"
#define SDCARD_CS_PIN               GPIO_NUM_1
#define SDCARD_MISO_PIN             SPI2_MISO_PIN
#define SDCARD_MOSI_PIN             SPI2_MOSI_PIN
#define SDCARD_CLK_PIN              SPI2_CLK_PIN





#define DISPLAY_WIDTH                   320
#define DISPLAY_HEIGHT                  480
#define DISPLAY_MIRROR_X                false
#define DISPLAY_MIRROR_Y                false
#define DISPLAY_SWAP_XY                 false
#define DISPLAY_INVERT_COLOR            true
#define DISPLAY_RGB_ORDER               LCD_RGB_ELEMENT_ORDER_BGR
#define DISPLAY_OFFSET_X                0
#define DISPLAY_OFFSET_Y                0
#define DISPLAY_BACKLIGHT_OUTPUT_INVERT false
#define DISPLAY_SPI_MODE                0



// A MCP Test: Control a lamp
#define LAMP_GPIO GPIO_NUM_18

#endif // _BOARD_CONFIG_H_

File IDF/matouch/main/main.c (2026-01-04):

#include <stdio.h>
#include <nvs.h>
#include <nvs_flash.h>
#include <esp_log.h>
#include <esp_event.h>
#include <esp_sntp.h>
#include <time.h>

#include <freertos/FreeRTOS.h>
#include <freertos/task.h>

#include "protocol_examples_common.h"

static const char *TAG = "main";

extern void board_init(void);
extern void release_demo(void);

static void get_sntp_time(void *arg)
{
    // Initialize ntp
    setenv("TZ", "CST-8", 1);
    tzset();
    ESP_LOGI(TAG, "Timezone set to CST-8");

    ESP_LOGI(TAG, "Initializing SNTP");
    esp_sntp_setoperatingmode(SNTP_OPMODE_POLL);
    esp_sntp_setservername(0, "ntp.aliyun.com");
    esp_sntp_init();
    ESP_LOGI(TAG, "SNTP initialized");

    time_t now = 0;
    struct tm timeinfo = { 0 };
    int retry = 0;
    const int retry_count = 20;
    while (retry < retry_count) {
        time(&now);
        localtime_r(&now, &timeinfo);
        if (timeinfo.tm_year > (2016 - 1900)) break;
        ESP_LOGI(TAG, "Waitting SNTP sync... (%d/%d)", retry + 1, retry_count);
        vTaskDelay(pdMS_TO_TICKS(1000));
        retry++;
    }

    char strftime_buf[64];

    time(&now);
    localtime_r(&now, &timeinfo);

    strftime(strftime_buf, sizeof(strftime_buf), "%c", &timeinfo);
    ESP_LOGI(TAG, "The current date/time in Shanghai is: %s", strftime_buf);

    vTaskDelete(NULL);
}
void app_main(void)
{
    // Initialize the default event loop
    // ESP_ERROR_CHECK(esp_event_loop_create_default());

    // Initialize NVS flash for WiFi configuration
    // esp_err_t ret = nvs_flash_init();
    // if (ret == ESP_ERR_NVS_NO_FREE_PAGES || ret == ESP_ERR_NVS_NEW_VERSION_FOUND) {
    //     ESP_LOGW(TAG, "Erasing NVS flash to fix corruption");
    //     ESP_ERROR_CHECK(nvs_flash_erase());
    //     ret = nvs_flash_init();
    // }
    // ESP_ERROR_CHECK(ret);

    board_init();

    release_demo();

    // ESP_ERROR_CHECK(esp_netif_init());
    // ESP_ERROR_CHECK(esp_event_loop_create_default());
    // ESP_ERROR_CHECK(example_connect());

    // xTaskCreate(get_sntp_time, "get_sntp_time", 4096, NULL, 6, NULL);

}

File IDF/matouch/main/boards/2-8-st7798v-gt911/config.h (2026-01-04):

#ifndef _BOARD_CONFIG_H_
#define _BOARD_CONFIG_H_

#include <driver/gpio.h>

#define AUDIO_INPUT_SAMPLE_RATE  16000
#define AUDIO_OUTPUT_SAMPLE_RATE 24000

#define SPI2_MOSI_PIN   GPIO_NUM_13
#define SPI2_MISO_PIN   GPIO_NUM_12
#define SPI2_CLK_PIN    GPIO_NUM_48

#define SPI3_MOSI_PIN   GPIO_NUM_13
#define SPI3_MISO_PIN   GPIO_NUM_12
#define SPI3_CLK_PIN    GPIO_NUM_14

// 如果使用 Duplex I2S 模式，请注释下面一行
#define AUDIO_I2S_METHOD_SIMPLEX

#ifdef AUDIO_I2S_METHOD_SIMPLEX

#define AUDIO_I2S_MIC_GPIO_WS   GPIO_NUM_2
#define AUDIO_I2S_MIC_GPIO_SCK  GPIO_NUM_42
#define AUDIO_I2S_MIC_GPIO_DIN  GPIO_NUM_41
#define AUDIO_I2S_SPK_GPIO_DOUT GPIO_NUM_19
#define AUDIO_I2S_SPK_GPIO_BCLK GPIO_NUM_20
#define AUDIO_I2S_SPK_GPIO_LRCK GPIO_NUM_1

#else

#define AUDIO_I2S_GPIO_WS GPIO_NUM_4
#define AUDIO_I2S_GPIO_BCLK GPIO_NUM_5
#define AUDIO_I2S_GPIO_DIN  GPIO_NUM_6
#define AUDIO_I2S_GPIO_DOUT GPIO_NUM_7

#endif


#define BUILTIN_LED_GPIO            GPIO_NUM_NC
#define BOOT_BUTTON_GPIO            GPIO_NUM_0
#define TOUCH_BUTTON_GPIO           GPIO_NUM_NC
#define VOLUME_UP_BUTTON_GPIO       GPIO_NUM_NC
#define VOLUME_DOWN_BUTTON_GPIO     GPIO_NUM_NC


#define DISPLAY_BACKLIGHT_PIN       GPIO_NUM_45
#define DISPLAY_MOSI_PIN            SPI2_MOSI_PIN
#define DISPLAY_MISO_PIN            SPI2_MISO_PIN
#define DISPLAY_CLK_PIN             SPI2_CLK_PIN
#define DISPLAY_DC_PIN              GPIO_NUM_21
#define DISPLAY_RST_PIN             GPIO_NUM_NC
#define DISPLAY_CS_PIN              GPIO_NUM_40

#define DISPLAY_WIDTH                       320
#define DISPLAY_HEIGHT                      240
#define DISPLAY_MIRROR_X                    true
#define DISPLAY_MIRROR_Y                    false
#define DISPLAY_SWAP_XY                     true
#define DISPLAY_INVERT_COLOR                true
#define DISPLAY_RGB_ORDER                   LCD_RGB_ELEMENT_ORDER_RGB
#define DISPLAY_OFFSET_X                    0
#define DISPLAY_OFFSET_Y                    0
#define DISPLAY_BACKLIGHT_OUTPUT_INVERT     false
#define DISPLAY_SPI_MODE                    0

#define TOUCH_SDA_PIN       GPIO_NUM_39
#define TOUCH_SCL_PIN       GPIO_NUM_38
#define TOUCH_INT_PIN       GPIO_NUM_14
#define TOUCH_RST_PIN       GPIO_NUM_18

#define SDCARD_MOUNT_POINT          "/sdcard"
#define SDCARD_CS_PIN               GPIO_NUM_47
#define SDCARD_MISO_PIN             SPI2_MOSI_PIN
#define SDCARD_MOSI_PIN             SPI2_MOSI_PIN
#define SDCARD_CLK_PIN              SPI2_CLK_PIN



// A MCP Test: Control a lamp
#define LAMP_GPIO GPIO_NUM_18

#endif // _BOARD_CONFIG_H_

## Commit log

2025-04-01 Add Arduino GFX Library demo
2025-11-20 add esp-idf examples
    [partitions.csv]
2026-01-04 update idf example
    [jconfig.txt, partitions.csv]
2026-01-04 delect example/esp-idf
    [partitions.csv]

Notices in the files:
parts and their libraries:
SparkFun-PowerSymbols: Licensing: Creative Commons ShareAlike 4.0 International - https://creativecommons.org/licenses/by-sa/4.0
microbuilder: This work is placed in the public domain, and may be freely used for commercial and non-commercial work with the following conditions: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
